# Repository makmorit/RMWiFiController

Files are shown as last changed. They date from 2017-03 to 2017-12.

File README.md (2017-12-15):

# RMWiFiController

## 概要

鉄道模型のレイアウト上（または近く）に配置したコントローラーを、手元のリモコンで操作する装置です。

## 構成

大きく分けるとパワーコントローラー部、リモコン部からなります。

これらに、Wi-Fiモジュールをそれぞれ搭載させ、制御データを同期させています。

基本的に内部機能は同一なので、コードは共用してます。

### コントローラー基板

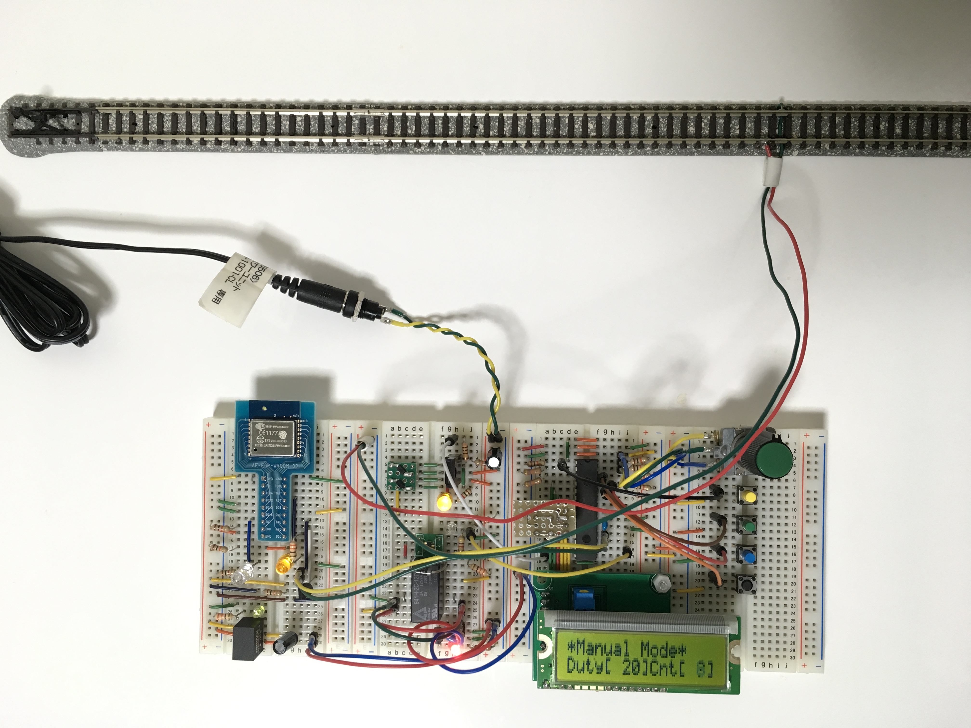
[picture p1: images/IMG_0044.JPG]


リモコンからのリモート制御用信号を、Wi-Fiモジュール（Arduino）で受けます。

PICマイコン（PIC16F18857。以下同）で、指定されたDuty比をもとにPWM信号を生成し、パワーMOSFETをドライブして駆動電圧を生成してます。

Duty比はリモコン基板でも、コントローラー基板上のつまみでも、どちらでも調整が可能です。

### リモコン基板

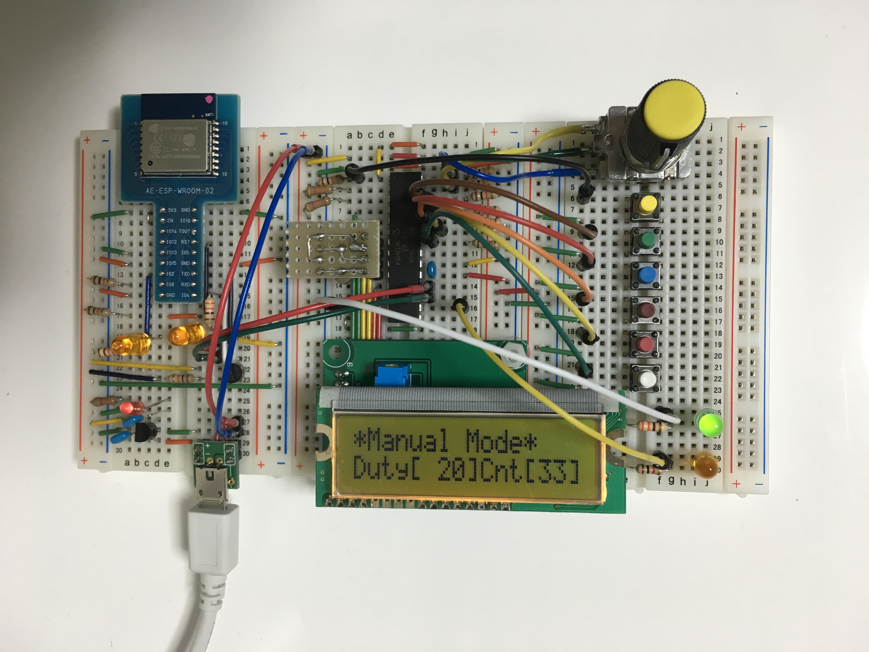
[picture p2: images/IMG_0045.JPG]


リモコン基板上のつまみで、Duty比を調整し、Wi-Fiモジュール（Arduino）からコントローラー基板へ送信します。

ただし、コントローラー基板と同じファームを使用しているので、ここでもPWM信号が生成され、その電圧でLEDを点灯させています（すなわちDuty比の大小でLEDが明るくなったり暗くなったりします）。

## 回路

EAGLE で作成したものを公開しております。

まだ、実体配線図は作成途上ですが、回路図はブレッドボードの実験回路にて動作を確認済みです。

## 機能

2017/04/22現在、機能を再編成中です。

現在は下記機能のみの提供となります。

(1) 基板上のつまみ（ロータリーエンコーダー）で、フィーダーから供給する動力電圧を制御

(2) 基板上のボタン（タクトスイッチ）で、フィーダーの極性（正転／反転）を切替え

### 将来追加予定の機能

(1) ボタン運転 - 基板上に用意した専用ボタンを押すたびに、加速（-->あらかじめ決めておいた最高動力で定速走行）-->減速（-->あらかじめ決めておいた停止ぎりぎりの動力で徐行）-->停止、の流れで運転することができる機能です。

(2) ダイヤ運転 - あらかじめ用意した運転条件／運転間隔で、ボタン運転と同じ流れの運転が実行できる機能です。

(3) 条件設定 - 上記ボタン運転／ダイヤ運転の条件（諸々のパラメーター）を、液晶ディスプレイをみながら設定／変更できる機能です。

## タッチセンサーの配線レス化

TOMIXタッチセンサーから、コントローラーの配線を無線化して、レイアウト全体の配線を極限まで簡素化するプランがあります。

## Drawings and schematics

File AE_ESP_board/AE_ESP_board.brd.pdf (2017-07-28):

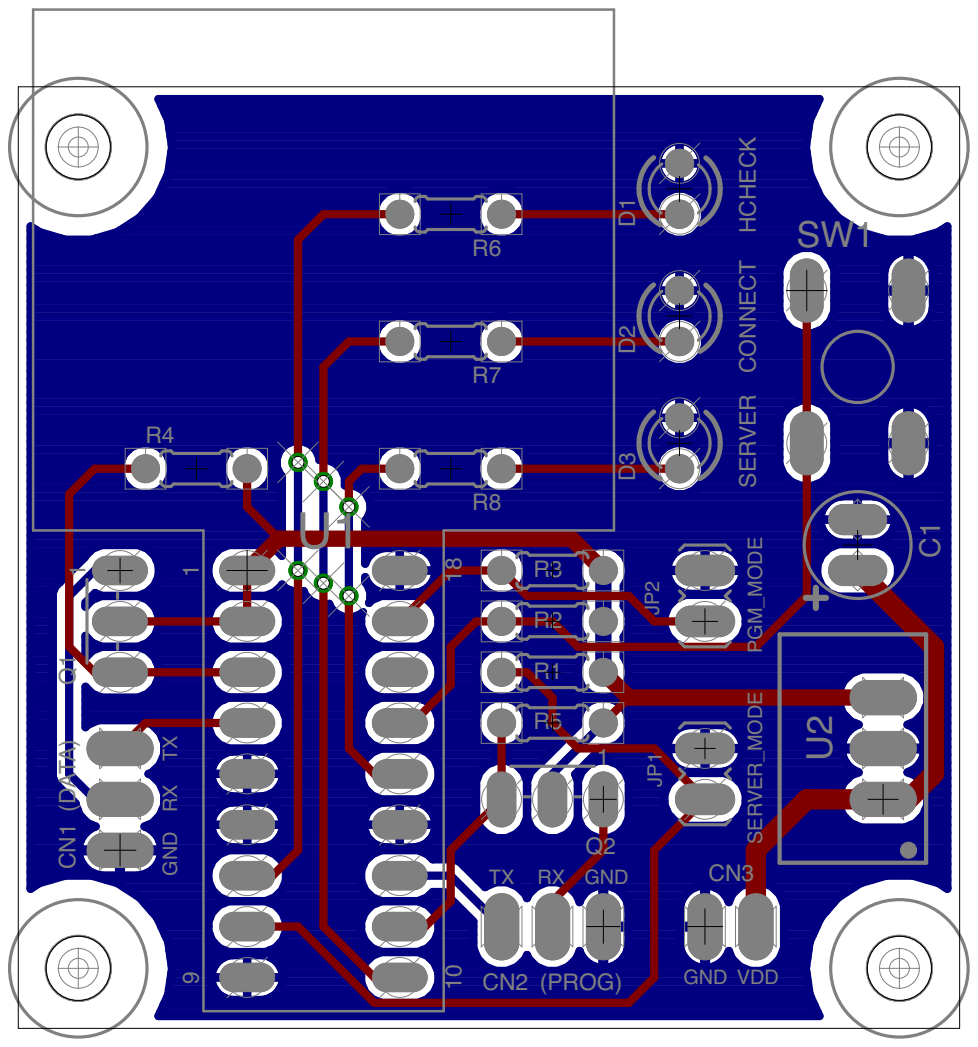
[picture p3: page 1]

PGM_MODE SERVER_MODE (PROG) (DATA) SERVER CONNECT HCHECK GND RX TX TX RX GND GND VDD 1 1 1 910 18C1 CN1 CN2 CN3 D1 D2 D3 JP1 JP2 Q1 Q2 R1 R2 R3 R4 R5 R6 R7 R8 SW1 U1 U2

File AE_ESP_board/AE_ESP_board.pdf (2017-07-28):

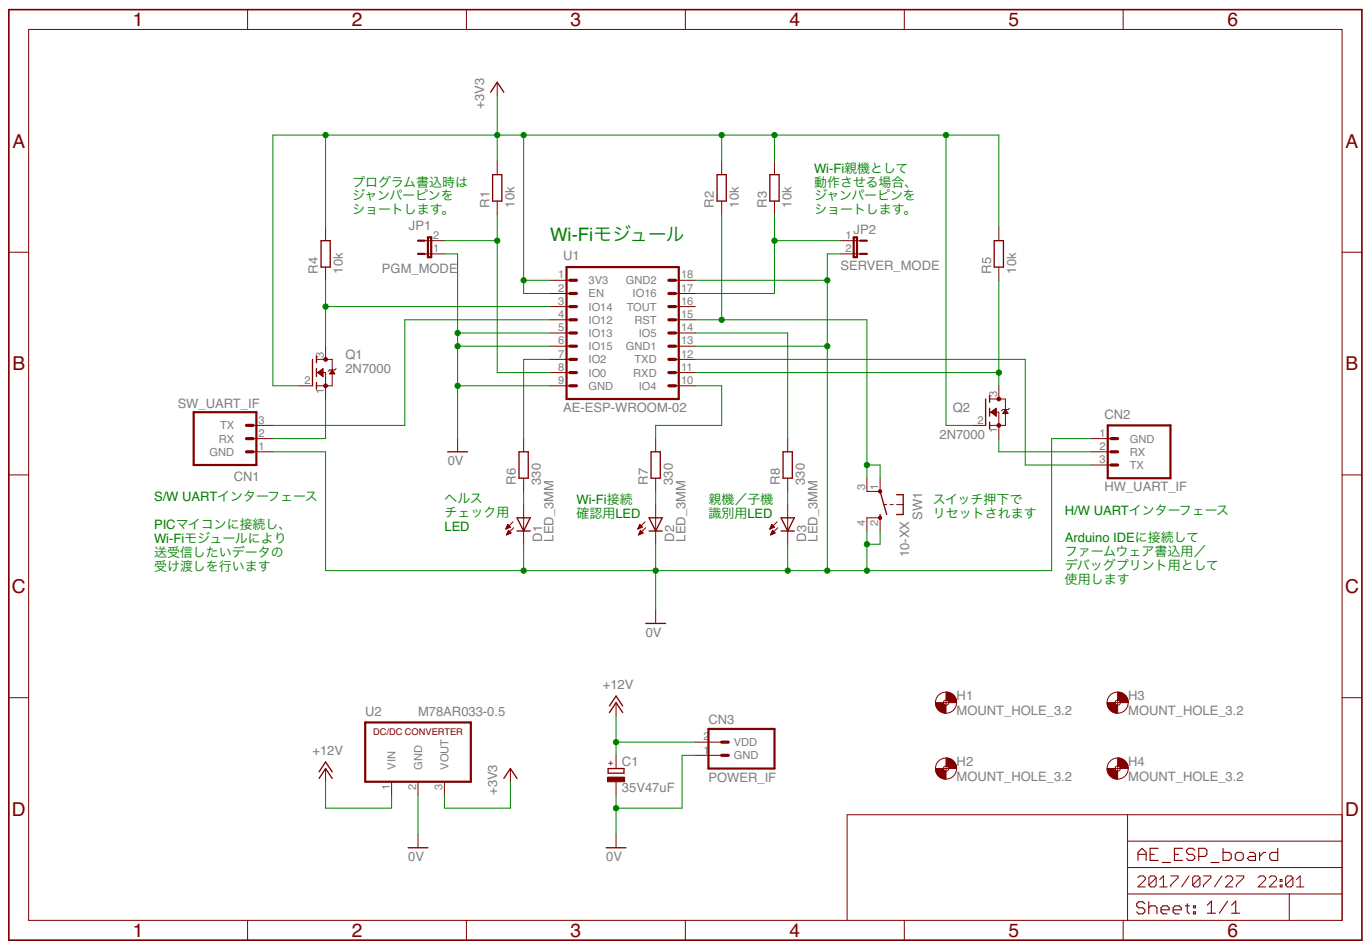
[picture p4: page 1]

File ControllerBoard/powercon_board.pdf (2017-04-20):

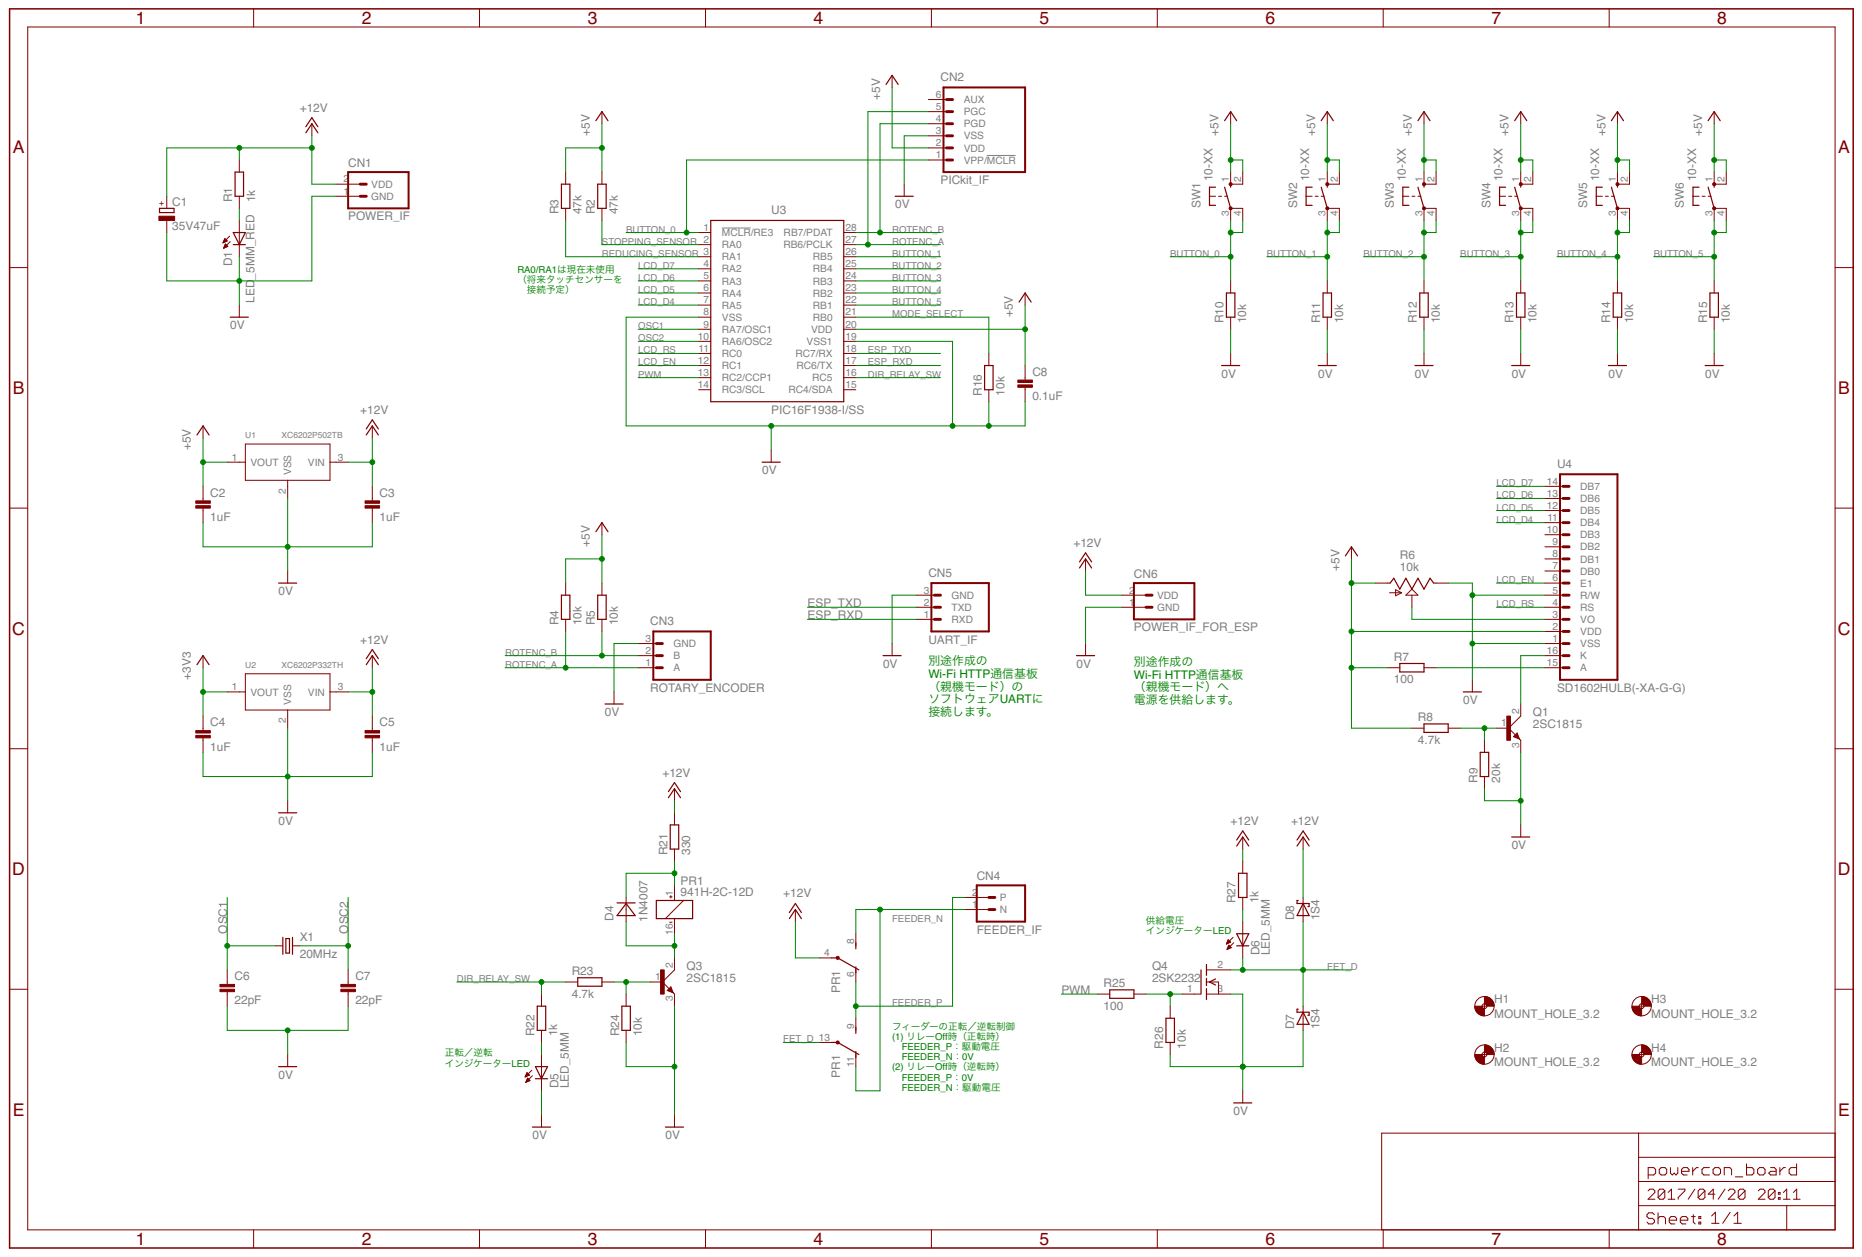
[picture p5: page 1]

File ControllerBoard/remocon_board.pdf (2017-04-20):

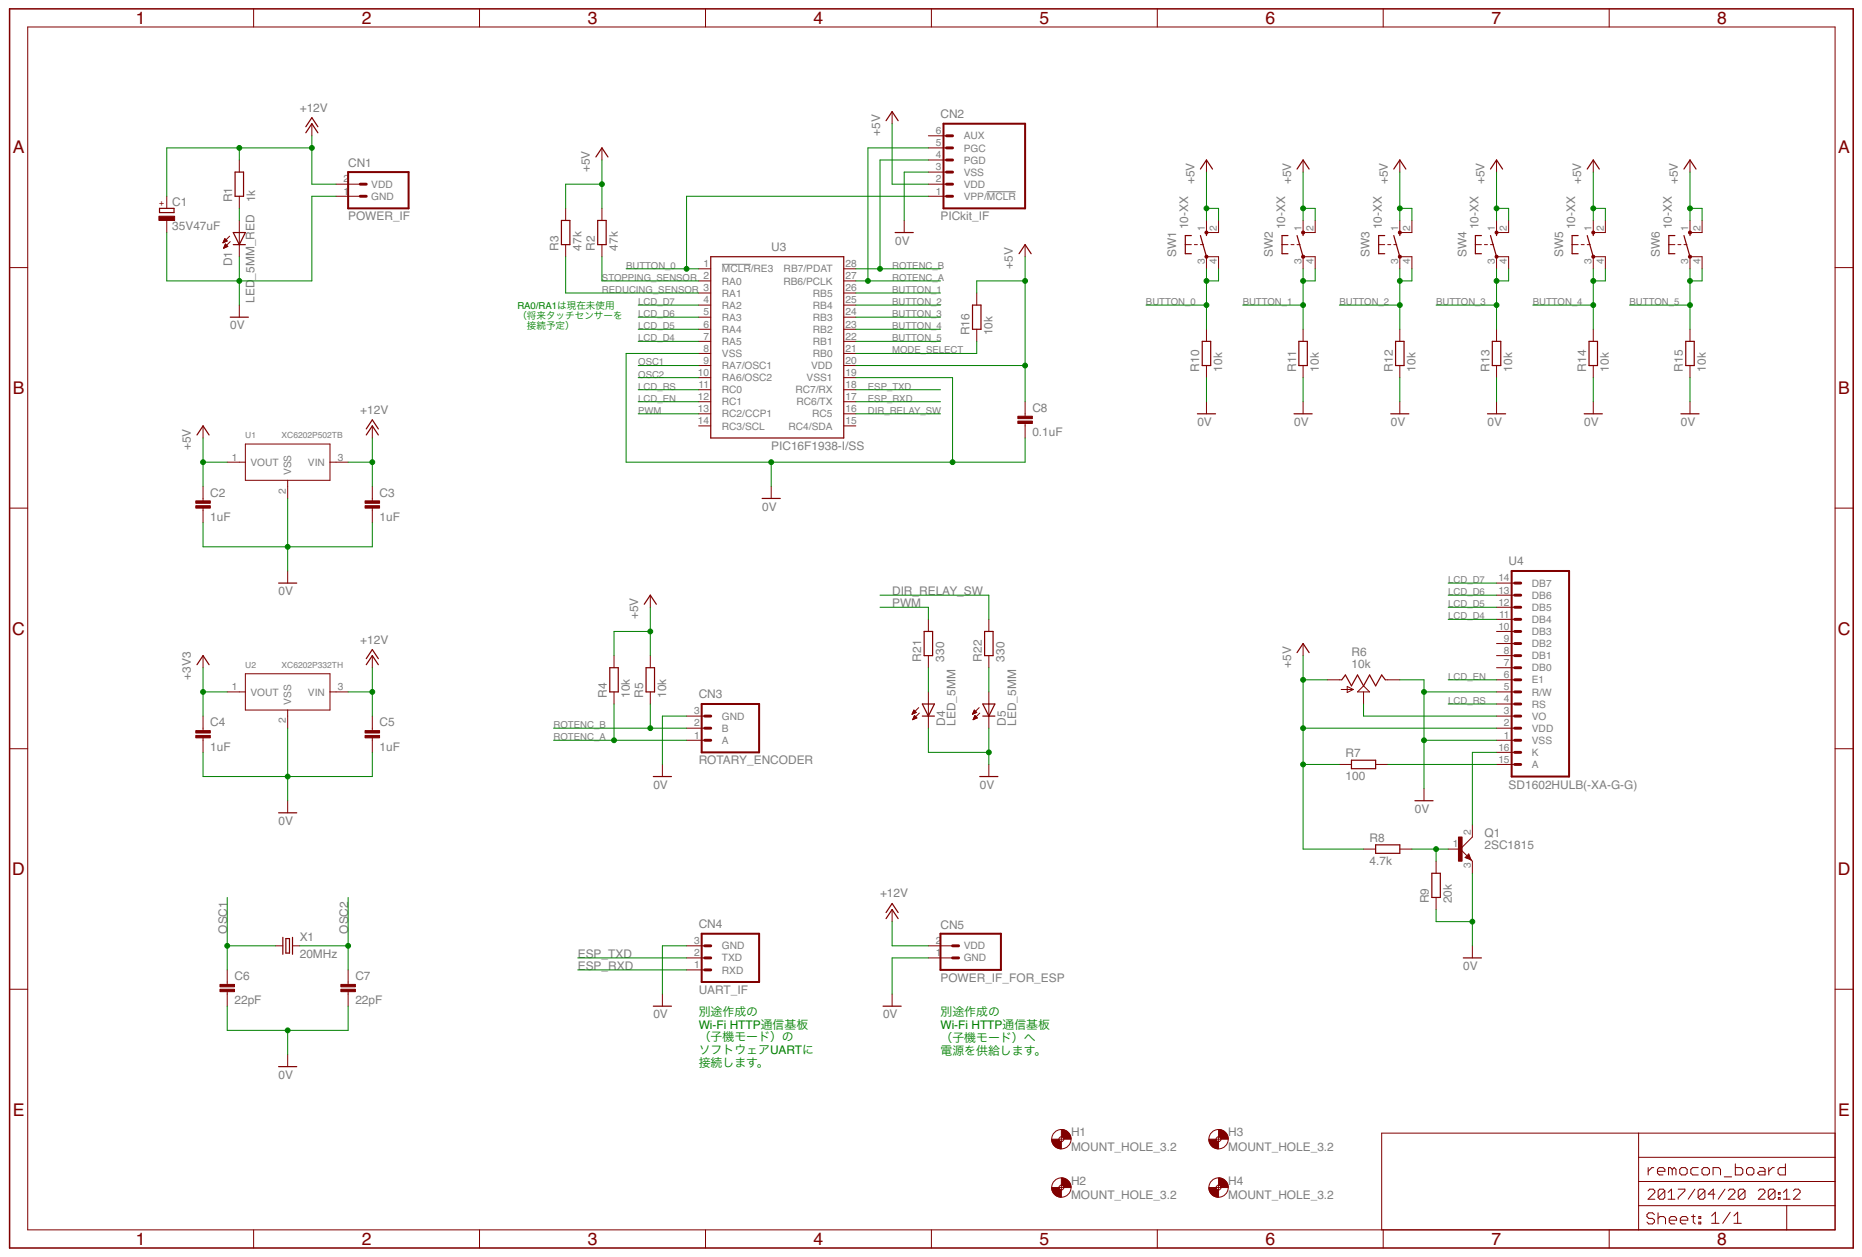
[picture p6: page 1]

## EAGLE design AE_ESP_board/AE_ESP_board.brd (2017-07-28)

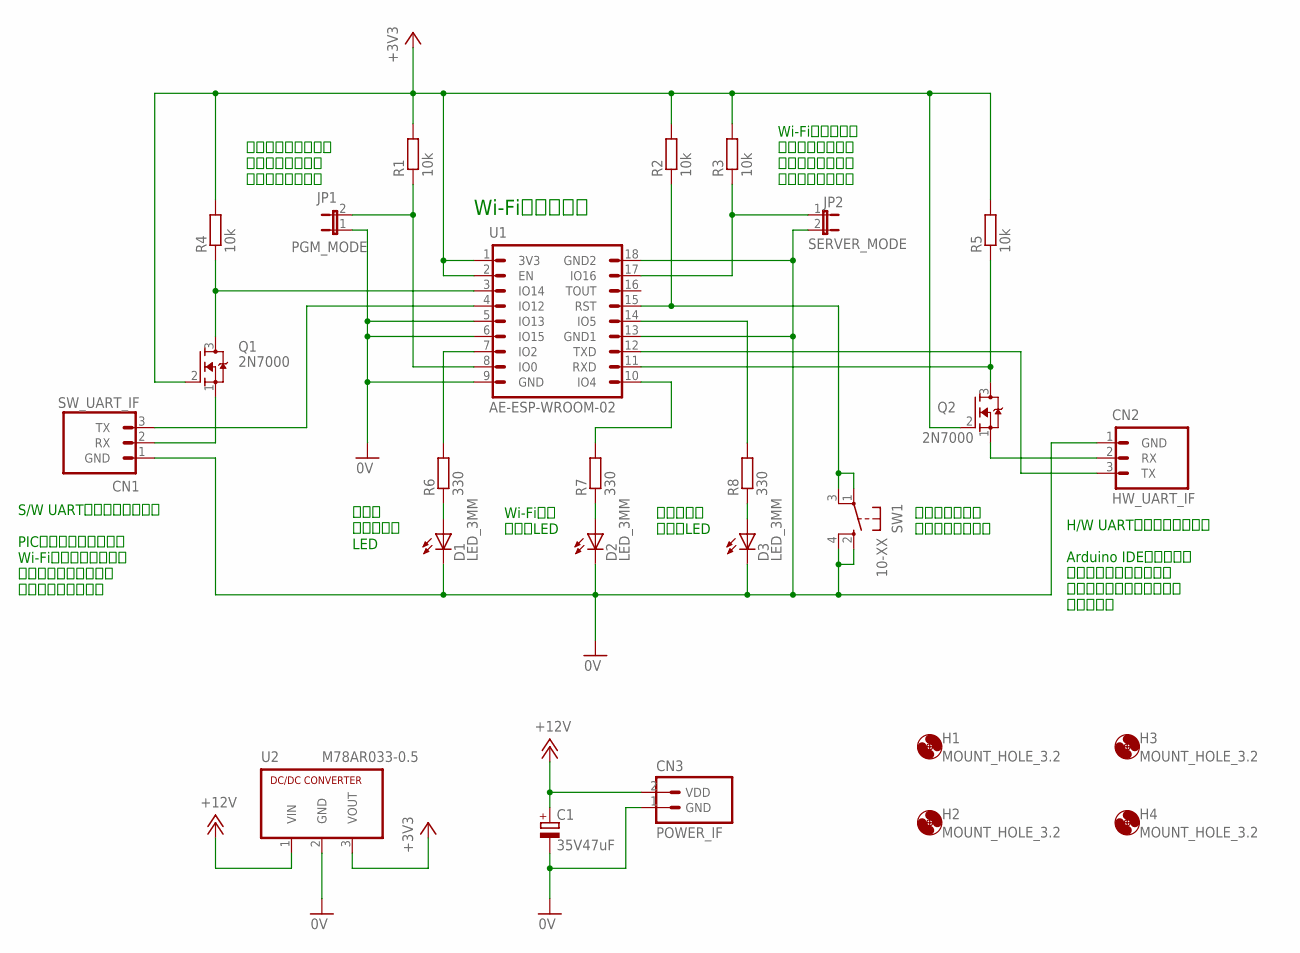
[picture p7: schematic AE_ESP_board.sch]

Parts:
C1: 35V47uF; ELECAP_D5_100MIL
CN1: SW_UART_IF; UART_IF_3PIN
CN2: HW_UART_IF; UART_IF_3PIN
CN3: POWER_IF; HEADER_2PIN_POWER_IF
D1, D2, D3: LED_3MM; LED3MM
H1, H2, H3, H4: MOUNT_HOLE_3.2; 3,2
JP1: PGM_MODE; JP1
JP2: SERVER_MODE; JP1
Q1, Q2: 2N7000; TO-92NL
R1, R2, R3, R4, R5: 10k; RESISTOR_0204_200MIL
R6, R7, R8: 330; RESISTOR_0204_200MIL
SW1: 10-XX; B3F-10XX
U1: AE-ESP-WROOM-02; DIL18_AE-ESP-WROOM-02
U2: M78AR033-0.5; SIP3

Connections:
0V: C1.-, CN1.1 (GND), CN2.1 (GND), CN3.1 (GND), D1.K (C), D2.K (C), D3.K (C), JP1.1, JP2.2, SW1.2 (S), SW1.4 (S1), U1.5 (IO13), U1.6 (IO15), U1.9 (GND), U1.13 (GND1), U1.18 (GND2), U2.2 (GND)
+3V3: Q1.2 (G), Q2.2 (G), R1.2, R2.2, R3.2, R4.2, R5.2, U1.1 (3V3), U1.2 (EN), U2.3 (VOUT)
+12V: C1.+, CN3.2 (VDD), U2.1 (VIN)
HW_UART_TXD: CN2.3 (TX), U1.12 (TXD)
LED_CONNECTING: R7.2, U1.10 (IO4)
LED_HCHECK: R6.2, U1.7 (IO2)
unnamed: CN1.3 (TX), U1.4 (IO12)
unnamed: JP2.1, R3.1, U1.17 (IO16)
unnamed: CN2.2 (RX), Q2.1 (S)
unnamed: R8.2, U1.14 (IO5)
unnamed: D3.A, R8.1
unnamed: Q2.3 (D), R5.1, U1.11 (RXD)
unnamed: JP1.2, R1.1, U1.8 (IO0)
unnamed: R2.1, SW1.1, SW1.3 (P1), U1.15 (RST)
unnamed: D2.A, R7.1
unnamed: D1.A, R6.1
SW_UART_RXD: CN1.2 (RX), Q1.1 (S)
SW_UART_RXD_IN: Q1.3 (D), R4.1, U1.3 (IO14)

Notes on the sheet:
プログラム書込時は ジャンパーピンを ショートします。
ヘルス チェック用 LED
Wi-Fi接続 確認用LED
スイッチ押下で リセットされます
Wi-Fiモジュール
H/W UARTインターフェース Arduino IDEに接続して ファームウェア書込用／ デバッグプリント用として 使用します
S/W UARTインターフェース PICマイコンに接続し、 Wi-Fiモジュールにより 送受信したいデータの 受け渡しを行います
Wi-Fi親機として 動作させる場合、 ジャンパーピンを ショートします。
親機／子機 識別用LED

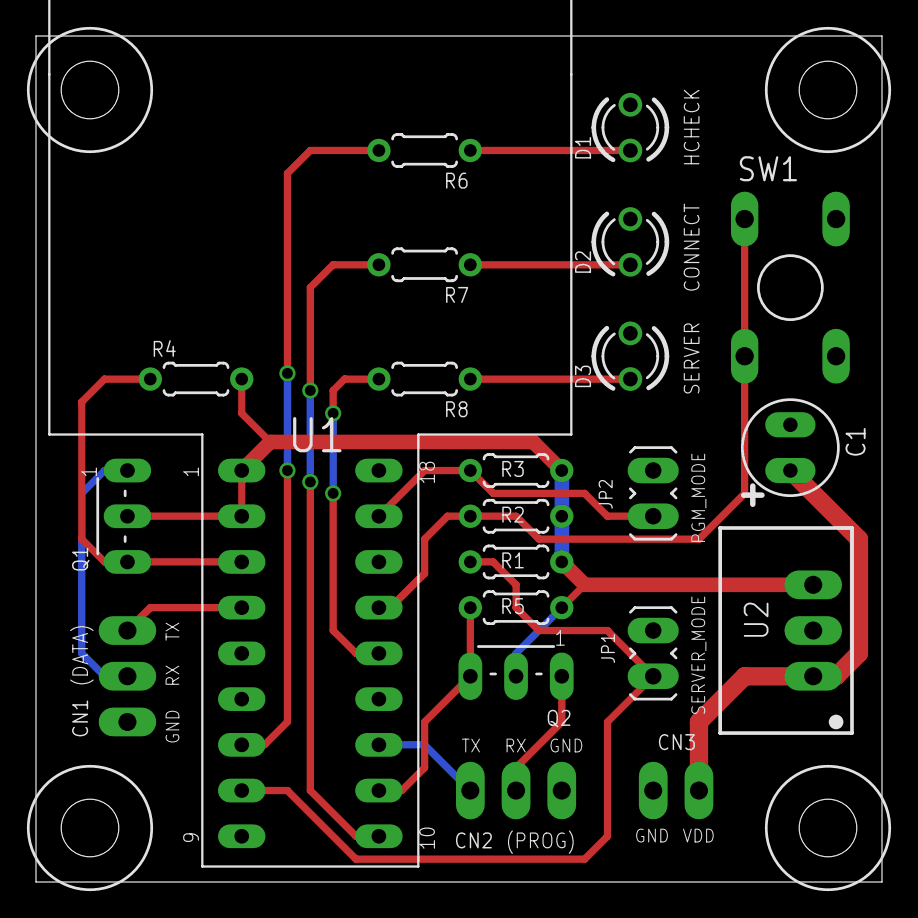
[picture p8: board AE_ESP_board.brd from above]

Board: 2 copper layers, 47.0 x 47.0 mm, 26 parts (0 on the bottom side), 18 nets.

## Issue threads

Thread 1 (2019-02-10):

[改善] ESP-WROOM-02カスタムボードを製作する

makmorit, 2019-02-10:
## 概要

秋月ボード＋ブレッドボードのまま２年間放置されているWi-Fiサーバー＆クライアント兼用ボードをプリント基板化します。

[秋月電子さんのESP-WROOM-02 DIP化キット](http://akizukidenshi.com/catalog/g/gK-09758/)が搭載されている下図ブレッドボード左側の部分を、独立した別のモジュールとして製作するものです。

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

### 将来的な用途

[鉄道模型コントローラー](../README.md)の、パワーコントローラー部、リモコン部で使用する予定です。
ただし、汎用的な作りにするので、他の用途にも使用できるかと思われます。

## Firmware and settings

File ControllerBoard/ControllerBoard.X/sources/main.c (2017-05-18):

#include "common.h"
#include "device.h"
#include "process.h"
#include "uart.h"
#include "timer0.h"
#include "timert2.h"
#include "lcd.h"

// CONFIG1
#pragma config FCMEN = OFF
#pragma config CSWEN = OFF
#pragma config CLKOUTEN = OFF
#pragma config RSTOSC = EXT1X // External Oscillator no PLL
#pragma config FEXTOSC = HS   // External Oscillator 20MHz
// CONFIG2
#pragma config STVREN = ON
#pragma config BORV = 1
#pragma config BOREN = ON
#pragma config PWRTE = ON
#pragma config MCLRE = OFF
// CONFIG3
#pragma config WDTE = OFF
// CONFIG4
#pragma config LVP = OFF
#pragma config WRT = OFF
// CONFIG5
#pragma config CPD = OFF
#pragma config CP = OFF

//
// 各種設定
//   ピン設定, TIME 0, UART, CCP
//
static void setup()
{
    // EXTOSC is explicitly enabled, 
    // operating as specified by FEXTOSC
    OSCENbits.EXTOEN = 1;

    setup_port();
    setup_timer0();
    setup_timer2();
    setup_uart();

    // 全割込み処理を許可
    PEIE = 1;
    GIE  = 1;
}

//
// 割込み処理
//   UART, TIMER 0
//
static void interrupt intr(void)
{
    uart_intr();
    timer0_intr();
}

//
// メインルーチン
//
void main() 
{
    // ピンや機能等の設定処理
    setup();

    // 初期化処理
    //   TIMER 0, CCP, UART, LCD
    timer0_init();
    uart_init();
    lcd_init();
    timer2_init();
    
    // 主処理ループで使用される変数の初期化
    process_init();

    // 主処理ループ
    while (1) {
        process();
    }
}

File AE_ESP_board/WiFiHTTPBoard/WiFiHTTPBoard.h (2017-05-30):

#ifndef __WIFI_HTTP_BOARD_H
#define __WIFI_HTTP_BOARD_H

#define BAUD_RATE  19200
#define WIFI_SVR_BEGIN_INTMS  500

#define WIFI_CLI_BEGIN_INTMS  250
#define WIFI_CLI_POLLING_INTMS  500

#define WIFI_URL_QUERY "/query/"

#define GPIO_HIGH 1
#define GPIO_LOW 0

#define PIN_LED_HCHECK 2
#define PIN_LED_CONNECTING 4
#define PIN_LED_SVRCLI 5
#define PIN_SVRCLI_MODE 16

#define PIN_SWSERIAL_RX 14
#define PIN_SWSERIAL_TX 12
#define PIN_SWSERIAL_GND 13

#endif // __WIFI_HTTP_BOARD_H

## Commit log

2017-03-02 PICマイコン用ファームウェアの初版
2017-03-02 Arduino用ファームウェアの初版
    RMWiFi.h へのシンボリックリンクが、各サブディレクトリー配下に別途必要になります。
2017-03-02 概要記述
2017-03-02 説明用画像
2017-03-02 概要更新
2017-03-03 EAGLE 部品ライブラリー初版登録
    データシートも為念で登録するようにします。
2017-03-04 PIC16F1938の部品データを追加
2017-04-06 ファイル整理
    共通利用ファイルを library_for_eagle リポジトリーに移動しました
2017-04-06 ファイルを整理
    不要ファイル削除
2017-04-09 固有部品の初版
2017-04-09 リモコン部の回路図初版
    [controller_board.sch]
2017-04-10 リモコン部のファイル名称変更
    [remocon_board.sch]
2017-04-10 固有部品を追加
    フィーダー接続用端子
2017-04-10 パワーコントローラー部の回路図初版
    [powercon_board.sch]
2017-04-11 Arduino用ファームウェアを更新
    RMWiFi.hを各サブディレクトリー配下に配置しています。
    （リンクを不要とするため）
2017-04-12 Arduinoソースコードを再編成
    ・フォルダー／ファイル構成の見直し
    ・コメントの見直し
    ・ヘルスチェックリクエストを、ブラウザーなどから発行した場合、親機だけでなく子機でもヘルスチェック用LEDがOn/Offできるように修正
2017-04-19 Arduinoが不要になったため削除
    別途作成のWi-Fi HTTP通信基板に接続する前提
2017-04-19 Wi-Fi部が不要になったため回路図から削除
    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
    [powercon_board.sch, remocon_board.sch]
2017-04-20 MODE_SELECT端子を新設
    ・PICのファームウェアを共通化する目的
    ・MODE_SELECT=LOWの場合は親機（パワーコントローラー部）
    ・MODE_SELECT=HIGHの場合は子機（リモコン部）
    ・ディレクトリー名を EAGLE —> ControllerBoardに改称
    [powercon_board.sch, remocon_board.sch]
2017-04-20 Wi-Fi HTTP通信基板の回路図／ファームウェア初版
    ・Wi-Fi部（AE-ESP-WROOM-02）の回路／ファームウェアを再構築
    ・親機／子機で同じ回路／ファームウェアを使用するよう修正
    [AE_ESP_board.brd, AE_ESP_board.sch]
2017-04-21 いったん機能削減してPICソースコードを再編成
2017-04-21 PICソースコードをさらに再編成
2017-04-21 再編成前のソースコードを削除
2017-04-27 [WIP] PIC16F18857用ソースコードの初版
    実機が未到着なので、動作確認できていません。
2017-04-28 設定の見直し
    ・タイマー２の設定をPIC16F18857/18877の仕様に整合させる
    ・タイマー０の設定が間違っていたため修正
    ・レジスター名称のコーディングを見直し
    [device.c, main.c]
2017-04-28 コメントがまちがっているので修正
2017-05-16 定数を変更
    SSID／パスフレーズ／IPアドレスを、Wi-Fi HTTPサーバーに固有な内容へ変更
2017-05-16 Wi-Fiアクセスポイントモードでの試験用コード
    APモードのロジックを、WiFiServerProcessに移設した後、元に戻す予定です。
2017-05-17 Wi-Fiアクセスポイントモードに変更
    ・APモードのロジックを、WiFiServerProcessに移設
    ・コメントを修正
    ・アクセスポイント／HTTPサーバー起動後の待ち時間を調整
    [WiFiHTTPBoard.h, WiFiServerProcess.cpp]
2017-05-18 コメントを修正
2017-06-15 ボードレイアウトを削除
    設計を全面的に見直しのため
    [AE_ESP_board.brd]
2017-06-15 回路図を修正
    150mA —> 500mAのCMOSレギュレーターに変更
    [AE_ESP_board.sch]
2017-06-16 PartsForProto.lbrをマージ
    こちらのPartsForProto.lbrは削除
2017-06-17 回路図を修正
    [AE_ESP_board.sch]
2017-06-17 レイアウトを修正
    [AE_ESP_board.brd]
2017-06-18 レイアウトを修正
    基板のサイズが間違っていたので修正
    LEDのキャプションを追加
    [AE_ESP_board.brd, AE_ESP_board.sch]
2017-07-24 レイアウトの見直し
    レイアウトを47mm x 47mm に縮小します。
    [AE_ESP_board.brd]
2017-07-25 レイアウトを大幅見直し
    [AE_ESP_board.brd, AE_ESP_board.sch]
2017-07-26 レイアウト見直し
    LED以外はリード部品とする
    [AE_ESP_board.brd, AE_ESP_board.sch]
2017-07-27 LEDを表面実装にする理由がないので、こちらもリード部品化 （ただし3mm砲弾型前提）
    [AE_ESP_board.brd, AE_ESP_board.sch]
2017-07-28 配線を確定
    [AE_ESP_board.brd]
2017-12-15 タッチセンサーの配線レス化についての記述を追加
